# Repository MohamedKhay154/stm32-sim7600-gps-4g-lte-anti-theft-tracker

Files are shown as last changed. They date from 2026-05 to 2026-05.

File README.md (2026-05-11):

# STM32 SIM7600 GPS Tracker

This hobby project is designed to be a practical gadget that can be used in daily life, whether you own an expensive bike or car and want to detect theft once it is parked, or simply want to track anything using GPS and cloud connectivity. 
In this project, I will explain how I developed and built the system.

---

# Overview
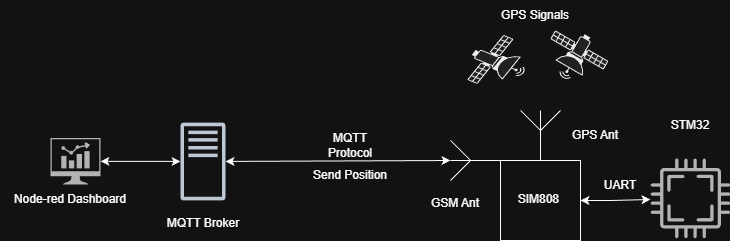
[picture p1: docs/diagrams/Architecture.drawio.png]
System architecture


The STM32 communicates with the SIM7600E module via UART. GPS data is parsed on the MCU and sent either via SMS or published to an MQTT broker. Node-RED processes incoming data and provides visualization and control.

---

# Features

- Custom PCB design
- GPS tracking
- MQTT publish/subscribe
- Geofence/Park mode
- Connection health monitoring
- Modular embedded software design

---

# Hardware
Since this project is intended to be a compact GPS tracker, I wanted to make it as small as possible while using the SIM7600E module. I decided to divide the hardware into two separate PCBs.

The first PCB contains the SIM7600E module and all the required supporting hardware, such as the SIM card holder, antennas, and its dedicated voltage regulator. The second PCB contains the STM32L072 microcontroller and the remaining supporting hardware components. Both PCBs are stacked together and communicate through a common connector interface.

Note: In this page, I will only discuss the SIM7600E board because the second board is still under development. I am currently adding extra features to it, such as a battery charging circuit and a gyroscope. Once it is completed, I will publish it as well. For now, I am using a Nucleo board for prototyping.

## Schematic
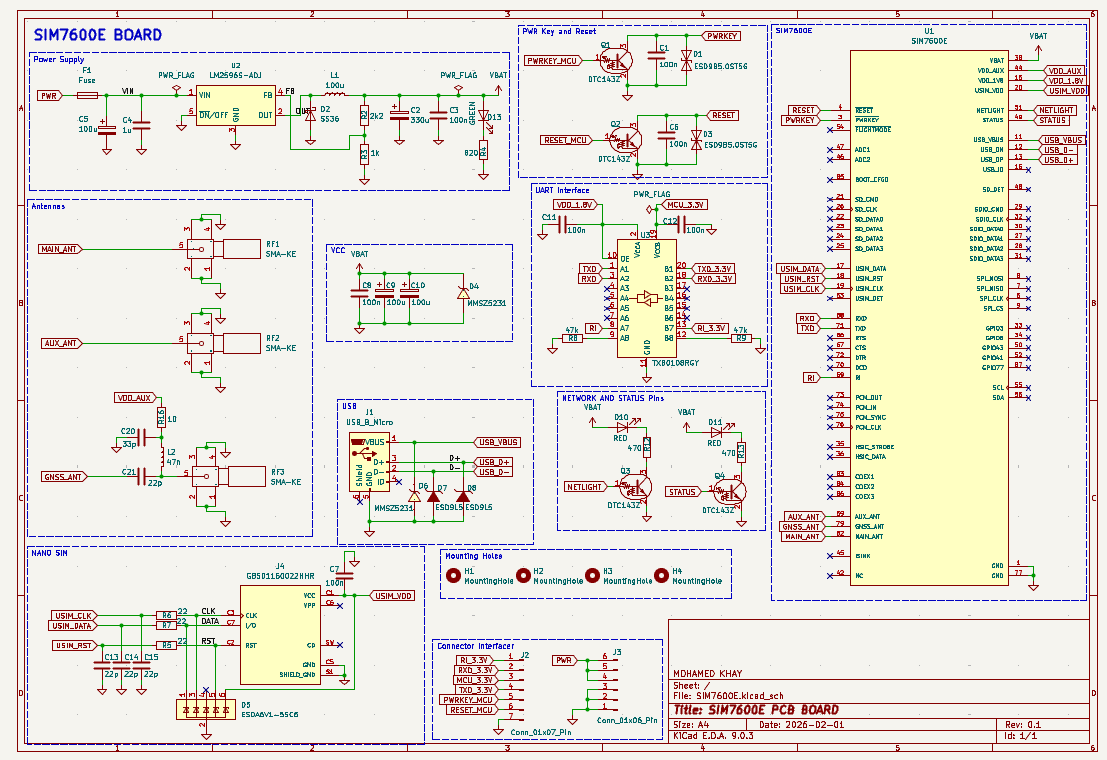
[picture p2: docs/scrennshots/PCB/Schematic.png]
Schematic


The first main step in designing a custom PCB is creating the schematic. The datasheet provided by SIMCom was very helpful, as it includes recommended circuits and components, which made the design process much simpler.

I used the same buck converter recommended in the datasheet, the LM2596S-ADJ, because the board is powered using a 2S LiPo battery, which can provide up to 8.4V when fully charged and around 7.4V typically.

A logic level shifter is used to convert the SIM7600E 1.8V logic levels to 3.3V logic levels, ensuring safe UART communication with the microcontroller.

For the antennas, I chose a much simpler design, except for the GPS antenna, which requires a so-called bias-tee circuit to properly power the active GPS antenna. This circuit was also recommended and explained in the SIMCom datasheet.

Some LEDs were also added to visualize the network status.

In general, the SIM7600E supports many additional features, such as an SD card interface, but I only implemented the features that were necessary for this project.

## Footprints and Layout
<p align="center">
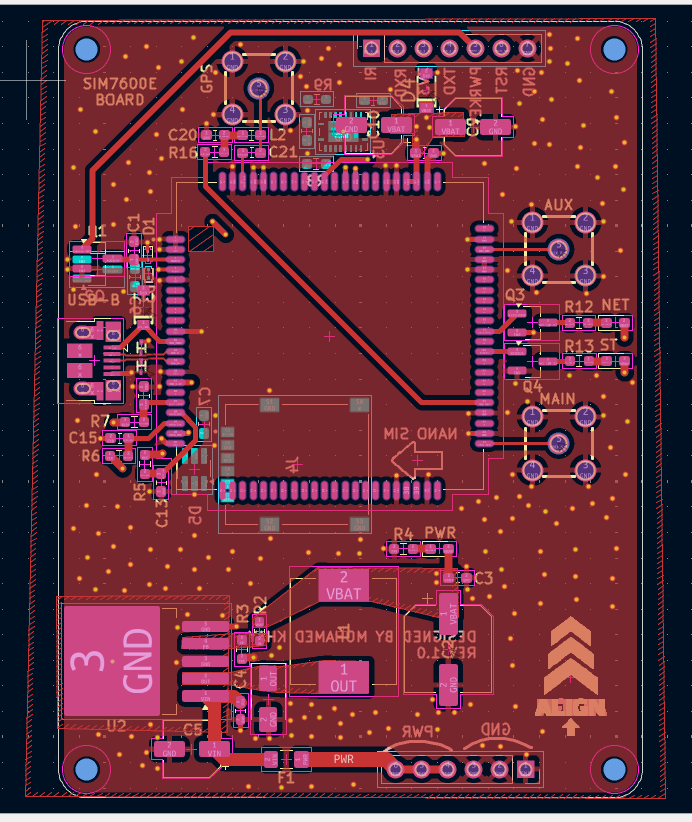
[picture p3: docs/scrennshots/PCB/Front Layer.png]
  
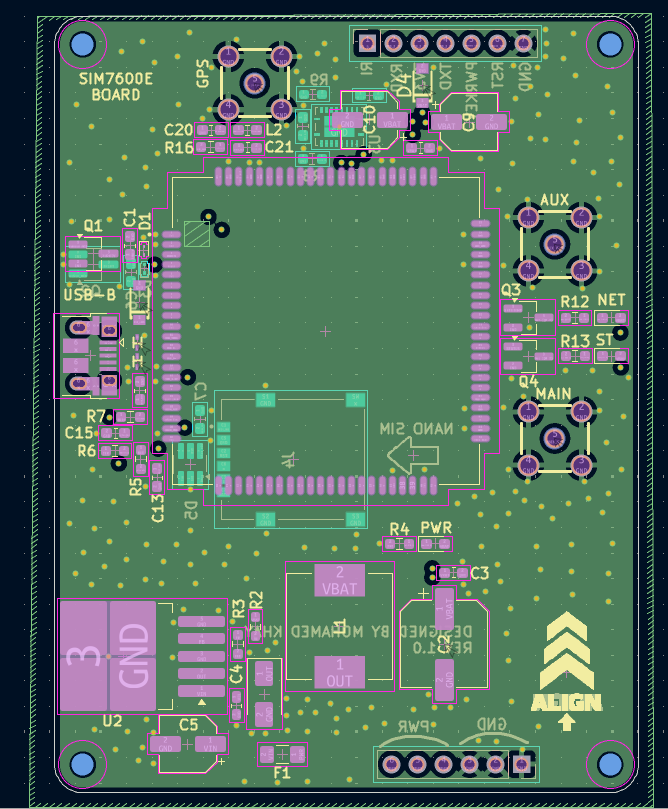
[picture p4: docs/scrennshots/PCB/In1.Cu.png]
  
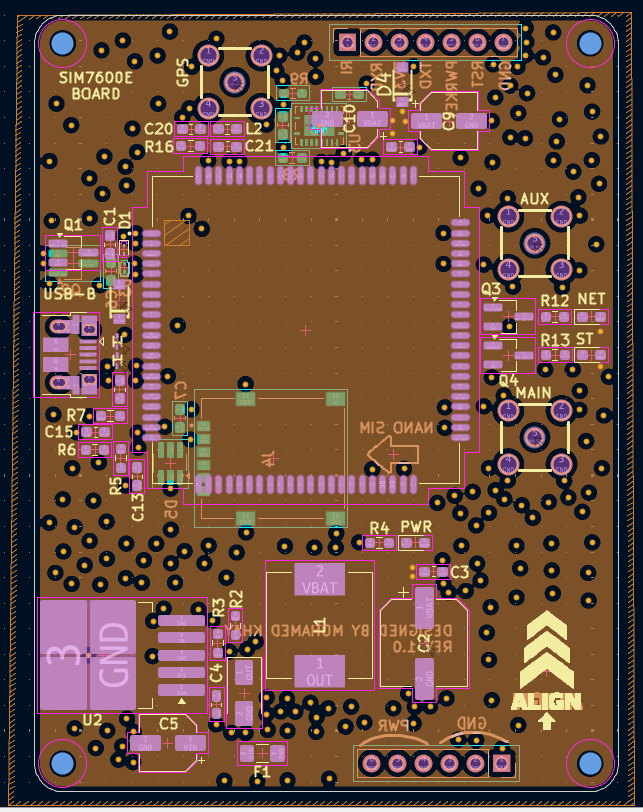
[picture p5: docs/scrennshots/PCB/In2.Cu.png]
  
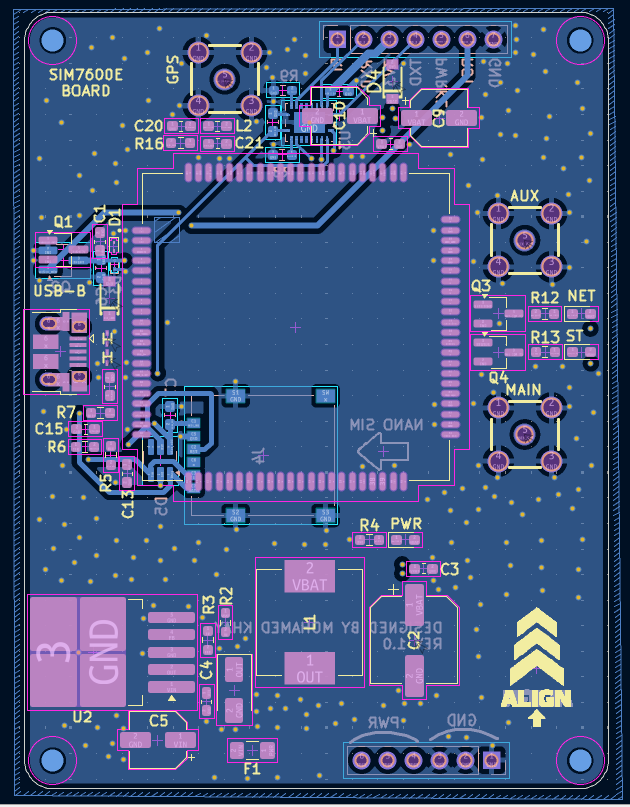
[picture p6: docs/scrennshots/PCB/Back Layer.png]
  
</p>

After reviewing the schematic, the next step is selecting the appropriate footprints. I have included the footprints I used, along with the symbols and 3D models, in the folder PCB Design/SIM7600E.

If this is your first time designing a PCB, like it was for me, avoid making the same mistake I did by choosing footprints that are too small for resistors, capacitors, and LEDs, especially if you plan to solder the board yourself.

For the PCB layout, I chose a 4-layer design to improve performance. The two inner layers are dedicated to the ground plane and power plane. 

This step is very important because a good PCB layout greatly affects the overall performance of the board, especially for the buck converter and high-frequency signals. 

## Manufacturing 

<p align="center">
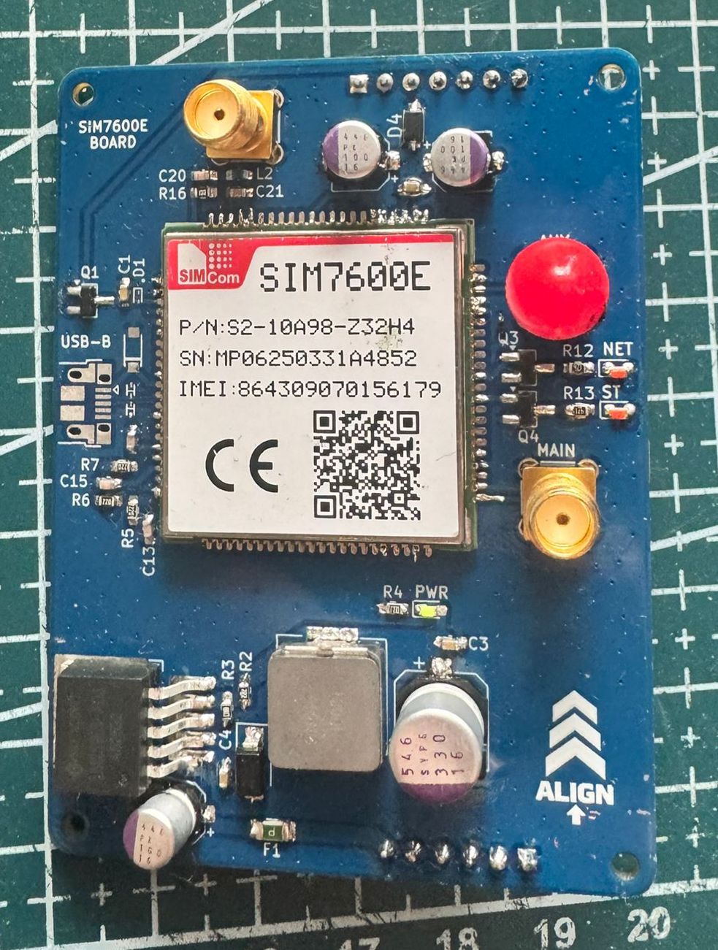
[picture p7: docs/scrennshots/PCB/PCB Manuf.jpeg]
  
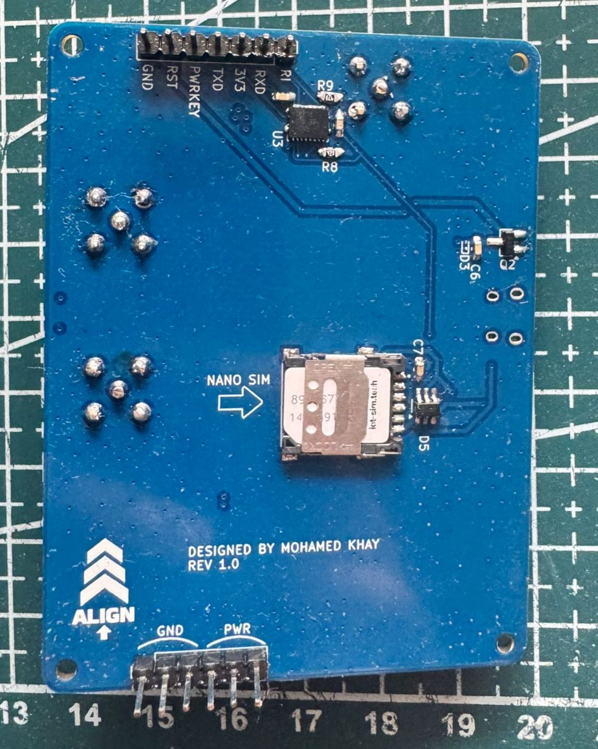
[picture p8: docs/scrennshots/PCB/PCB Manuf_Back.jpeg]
  
</p>

I ordered the PCB from JLCPCB and the components from LCSC, then soldered the board myself.

The BOM and component position files can be found here: `PCB Design/SIM7600E/production`

---

# Software Architecture

## Main Modules

```text
Core/
├── Inc/
  ├── min.h
  ├── SIM7600E.h
  ├── system_fsm.h
  ├── timer.h
  └── log.h
├── Src/
  ├── min.c
  ├── SIM7600E.c
  ├── system_fsm.c
  └── timer.c
```

`SIM7600.h` and `SIM7600.c` contain all the required functions to communicate with the SIM7600E module using UART, including GPS positioning, power control, SMS handling, and MQTT publish/subscribe functionality.

`system_fsm.h` and `system_fsm.c` contain the implementation of the finite state machine, which will be explained in the next section.

`timer.h` and `timer.c` contain the functions related to the timers used for tracking and system monitoring.

`log.h` contains an overridden version of the `printf` function used for logging general information, errors, and communication between the STM32 and the SIM7600E module for debugging purposes.

### Example of the logging interface during the TRACKING state.
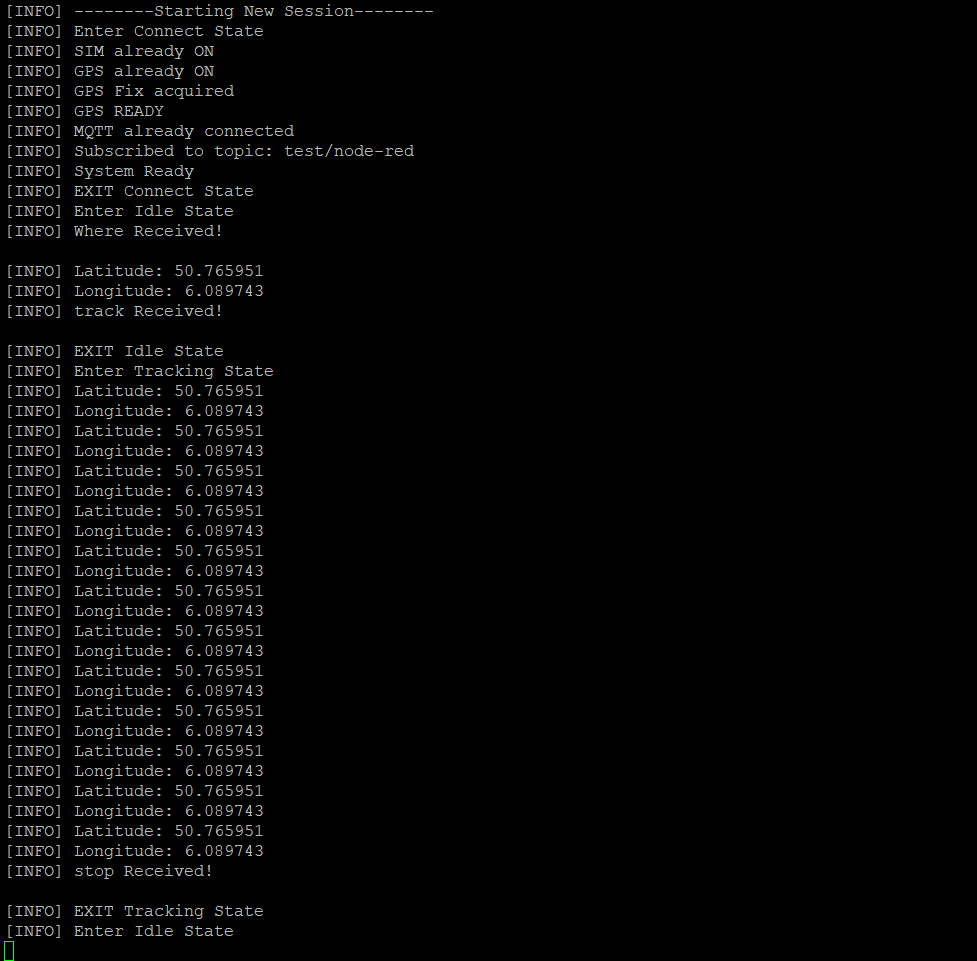
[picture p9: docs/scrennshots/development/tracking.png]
log


---

# State Machine

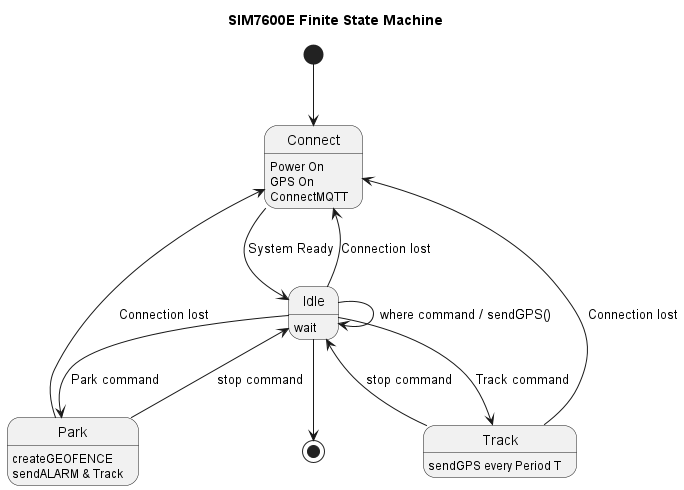
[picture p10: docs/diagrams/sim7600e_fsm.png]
FSM


The firmware uses an event-driven finite state machine.

## States

- CONNECT
- IDLE
- TRACK
- PARK

## Description

The CONNECT state is responsible for checking the status of the system components. It verifies whether the SIM module is powered, whether the network and MQTT connection are established, and whether the GPS is enabled. If any component is not ready, the state attempts to initialize or reconnect it accordingly. Once everything is ready, the system transitions to the IDLE state, where it waits for incoming events or commands.

If a `WHERE` command is received, the device immediately sends its current GPS position.

If a `TRACK` command is received, the system transitions to the TRACK state. In this state, a timer is started, and the device periodically sends its GPS position until a `STOP` command is received, after which the system returns to the IDLE state.

If a `PARK` command is received, the system transitions to the PARK state. First, the current GPS position is sent in order to create a geofence around the parked location (explained later in the Node-RED section). A timer is then started to continuously monitor the device position. If a geofence breach occurs, meaning the tracked device moves away from the allowed area, an alert is sent and the system automatically switches to TRACK mode since this may indicate a potential theft attempt.

In all states, another timer called `sysHealth_Timer` runs every 5 seconds to monitor the health of the communication stack. If a connection loss is detected in any state, the system automatically transitions back to the CONNECT state to recover the connection and then returns to the previous operational state.

## Why State Machine ?

Since this project is intended to work as an anti-theft tracker, it contains several different states and operating modes. Using a state machine makes the system more organized, prevents illogical scenarios, and makes the firmware easier to extend in the future.

For example, new subtasks, events, or operating modes can be added more easily. I also plan to allow the user to select these modes through hardware buttons, so having a state-machine-based architecture will make this feature easier to implement later.

---
# Node-Red
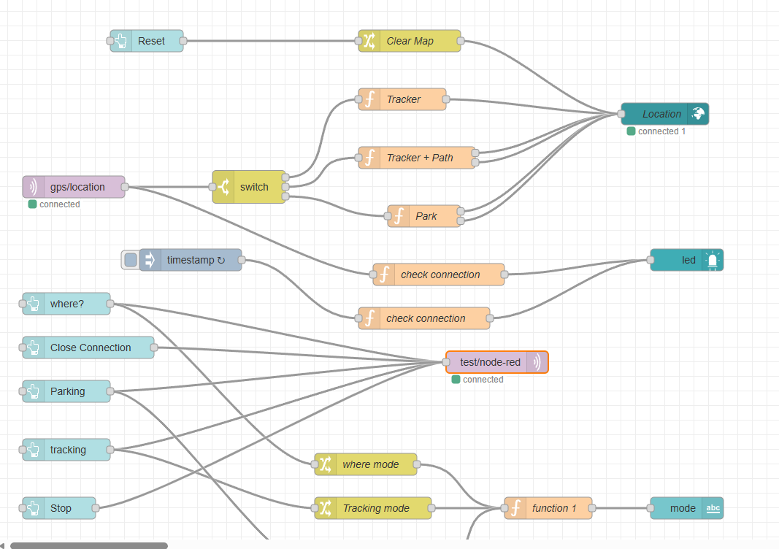
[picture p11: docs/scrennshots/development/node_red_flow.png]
Flow

Node-RED is widely used in IoT and network-related applications, and it supports the MQTT protocol natively. In addition, it is very easy to use and implement thanks to its drag-and-drop interface and simple JavaScript programming.

Node-RED subscribes to the same MQTT topic used by the SIM7600E module, receives the GPS position data, and then sends it as JSON data to a world map dashboard for visualization.

I also added support for different operating modes because each mode requires a specific type of visualization. For example, in TRACK mode, the system displays the traveled path, while in PARK mode, it creates a circular geofence around the parked position. The different visualizations are shown in the following pictures.

<p align="center">
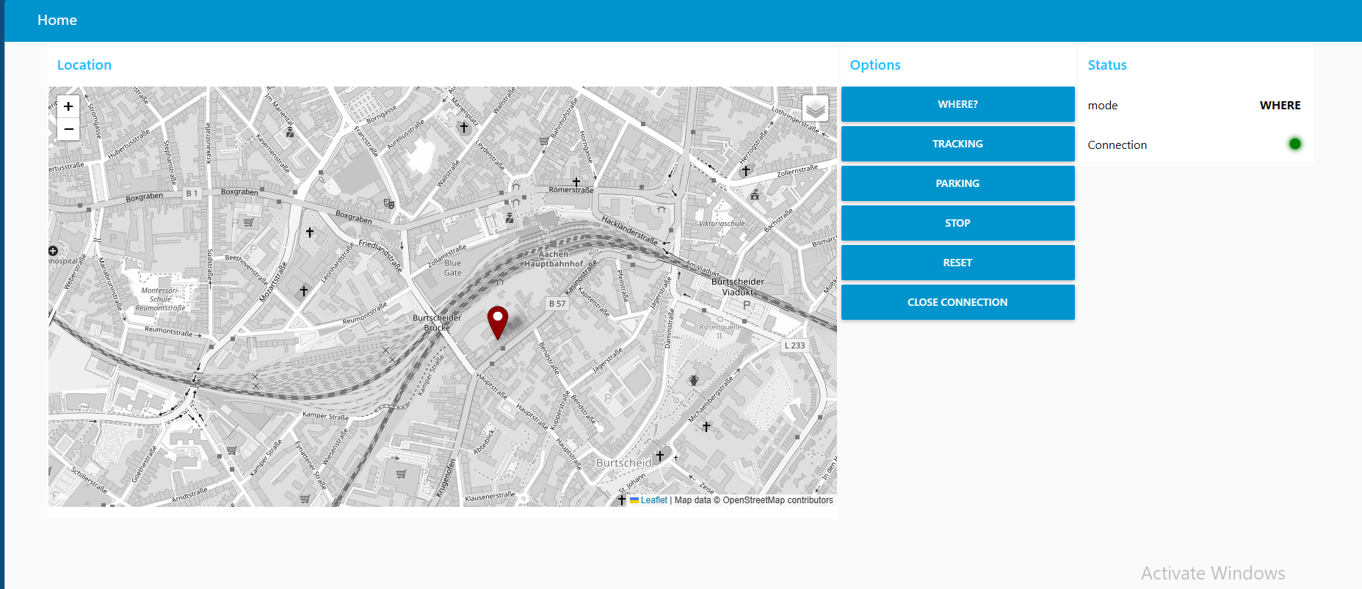
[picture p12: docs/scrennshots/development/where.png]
  
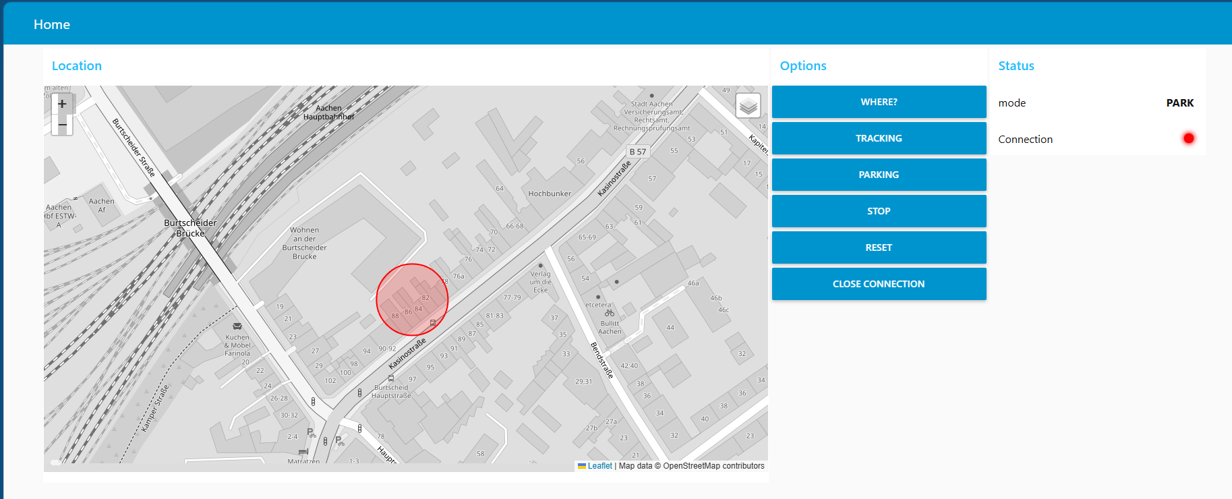
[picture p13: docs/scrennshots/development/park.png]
  
</p>

---

# Future Improvements

- Add a gyroscope/accelerometer for PARK mode in order to detect even the smallest movements. GPS data always has some tolerance and can sometimes vary by up to several meters, making it unreliable for immediate theft detection. By using a gyroscope or motion sensor, the system could instantly detect movement and then rely on GPS for long-distance tracking.
- Add a database to the Node-RED dashboard to give the project memory capabilities, allowing users to save and review previous trips, routes, and tracking history.
- Add battery monitoring functionality to the second PCB in order to monitor battery level and improve power management.

---

# Author

Mohamed Khay
Computer Engineering Student

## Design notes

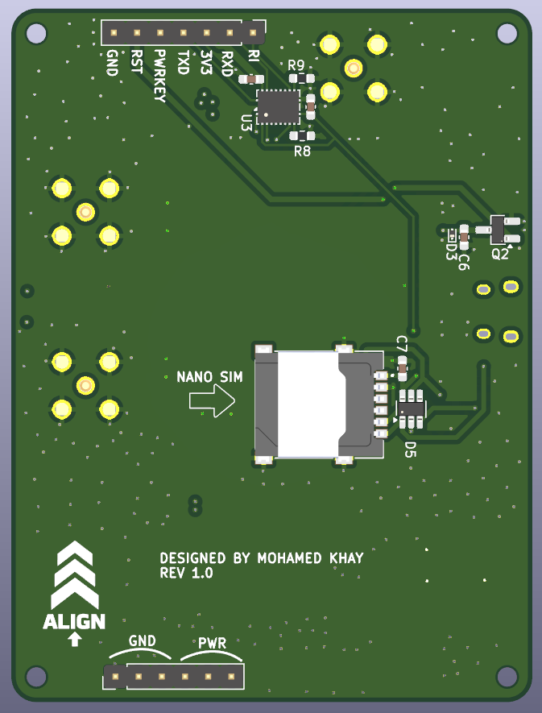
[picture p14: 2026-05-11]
docs/scrennshots/PCB/3D_Back.png

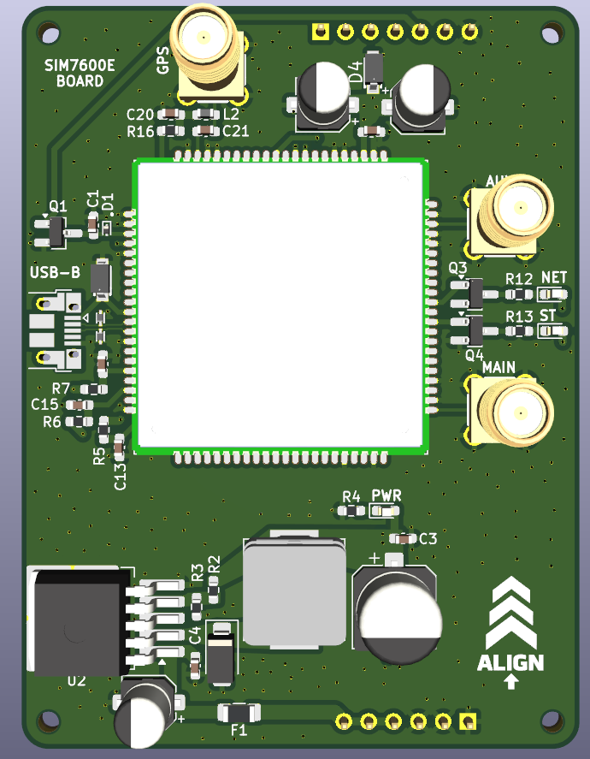
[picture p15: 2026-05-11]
docs/scrennshots/PCB/3D.png

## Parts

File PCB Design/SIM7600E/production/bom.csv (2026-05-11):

Designator | Footprint | Quantity | Value | LCSC Part #
C1, C11, C12, C3, C6, C7, C8 | 0603 | 7 | 100n
C10, C5, C9 | CP_Elec_5x5.9 | 3 | 100u
C13, C14, C15, C21 | 0603 | 4 | 22p
C2 | CP_Elec_8x6.9 | 1 | 330u
C20 | 0603 | 1 | 33p
C4 | 0603 | 1 | 1u
D1, D3 | D_SOD-923 | 2 | ESD9B5.0ST5G
D10, D11 | 0603 | 2 | RED
D13 | 0603 | 1 | GREEN
D2 | D_SMA | 1 | SS36
D4, D6 | SOD-123_L2.8-W1.8-LS3.7-RD | 2 | MMSZ5231
D5 | SOT-23-6_Handsoldering | 1 | ESDA6V1-5SC6
D7, D8 | SOD-923_L0.8-W0.6-LS1.0-RD | 2 | ESD9L5
F1 | 1206 | 1 | Fuse
J1 | USB_Micro-B_Amphenol_10103594-0001LF_Horizontal | 1 | USB_B_Micro
J2 | PinHeader_1x07_P2.54mm_Vertical | 1 | Conn_01x07_Pin
J3 | PinHeader_1x06_P2.54mm_Vertical | 1 | Conn_01x06_Pin
J4 | AMPHENOL_G85D1160022HHR | 1 | G85D1160022HHR
L1 | L_Vishay_IHLP-4040 | 1 | 100u
L2 | 0603 | 1 | 47n
Q1, Q2, Q3, Q4 | SOT-23_Handsoldering | 4 | DTC143Z
R12, R13 | 0603 | 2 | 470
R16 | 0603 | 1 | 10
R2 | 0603 | 1 | 2k2
R3 | 0603 | 1 | 1k
R4 | 0603 | 1 | 820
R5, R6, R7 | 0603 | 3 | 22
R8, R9 | 0603 | 2 | 47k
RF1, RF2, RF3 | SMA-TH_SMA-KE-5 | 3 | SMA-KE
U1 | XCVR_SIM7600E | 1 | SIM7600E
U2 | TO-263-5_TabPin3 | 1 | LM2596S-ADJ
U3 | Texas_RGY_R-PVQFN-N20_EP2.05x3.05mm | 1 | TXB0108RGY

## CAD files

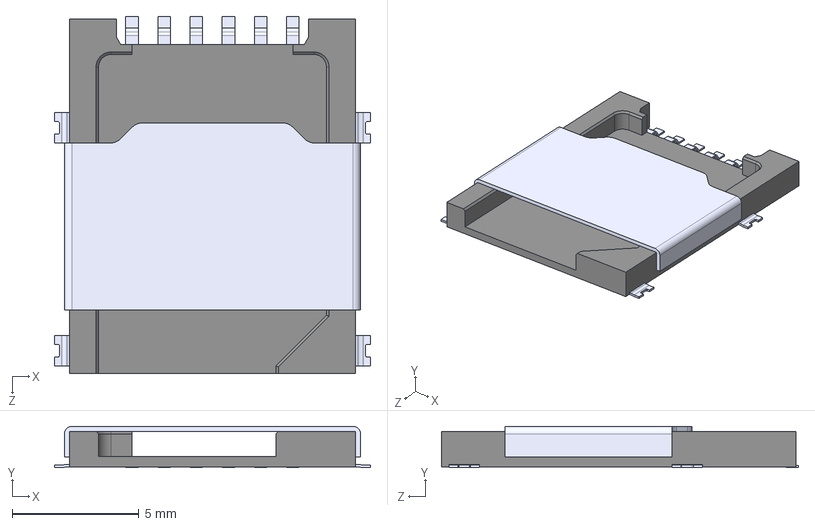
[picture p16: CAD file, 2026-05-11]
PCB Design/SIM7600E/SIM7600E_3D_MODELS/G85D1160022HHR.step
12.5 x 1.63 x 14.1 mm
G85D1160022HHR-Foot 0.5 x 6
G85D1160022HHR-Housing
G85D1160022HHR-shell
G85D1160022HHR-SW x 4

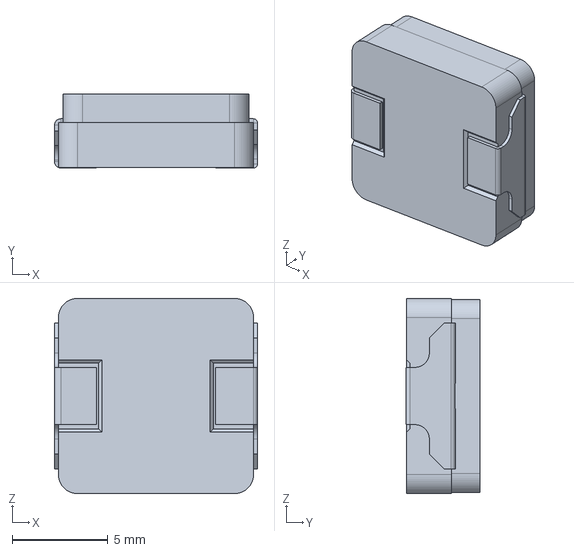
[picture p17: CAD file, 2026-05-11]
PCB Design/SIM7600E/SIM7600E_3D_MODELS/ihlp4040dzer101m11.stp
10.6 x 3.87 x 10.2 mm

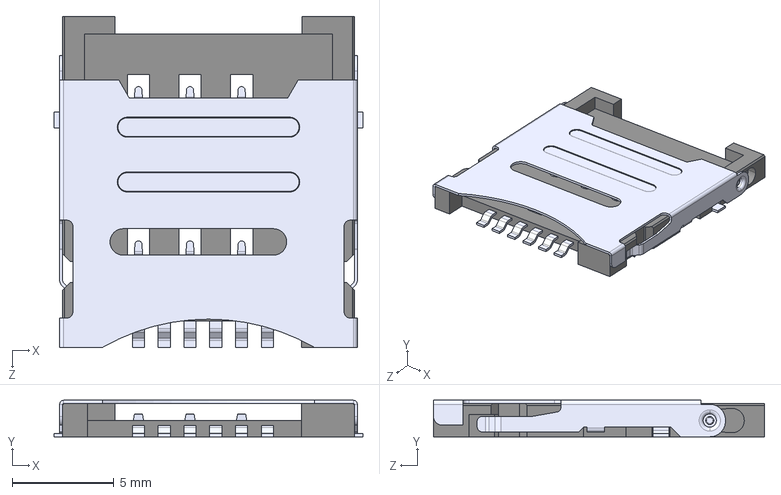
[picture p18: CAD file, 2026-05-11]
PCB Design/SIM7600E/SIM7600E_3D_MODELS/SMC-216.step
15.2 x 1.80 x 16.3 mm

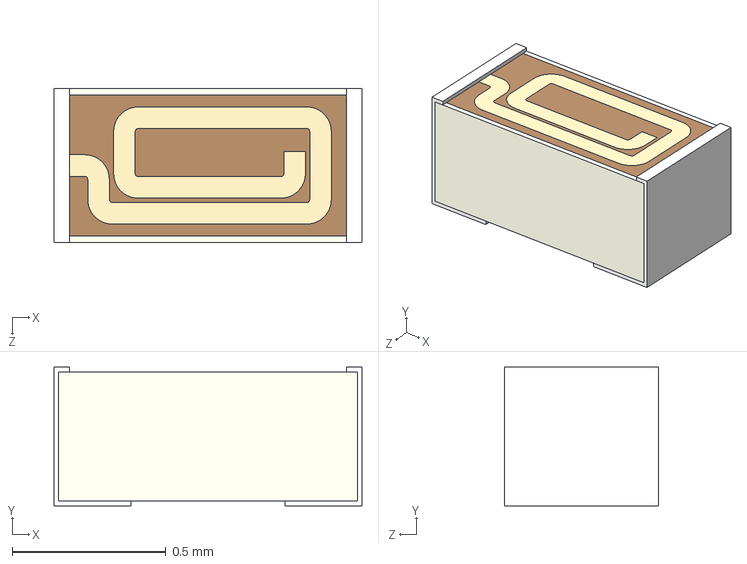
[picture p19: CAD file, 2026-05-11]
PCB Design/SIM7600E/SIM7600E_3D_MODELS/LXES15AAA1-153.STEP
1.00 x 0.45 x 0.5 mm

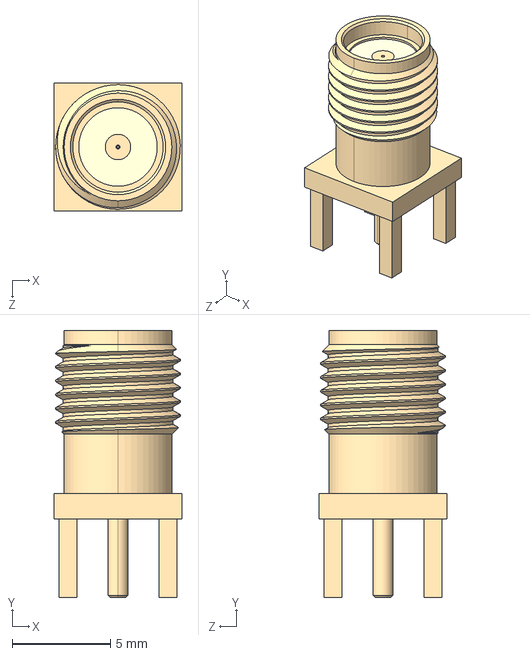
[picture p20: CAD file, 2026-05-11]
PCB Design/SIM7600E/SIM7600E_3D_MODELS/SMA_CONNECTOR.step
6.50 x 13.6 x 6.50 mm

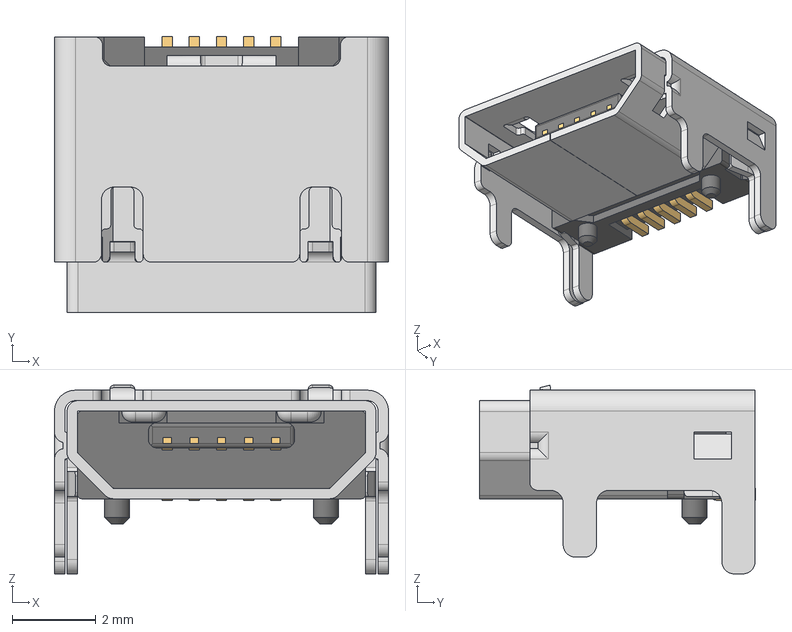
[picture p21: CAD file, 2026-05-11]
PCB Design/SIM7600E/SIM7600E_3D_MODELS/USB_Micro-B_629105150521.stp
8.00 x 6.60 x 4.52 mm
629105150521_Housing
629105150521_Pin1 x 4
629105150521_Pin2
629105150521_Shielding2
629105150521_Shielding

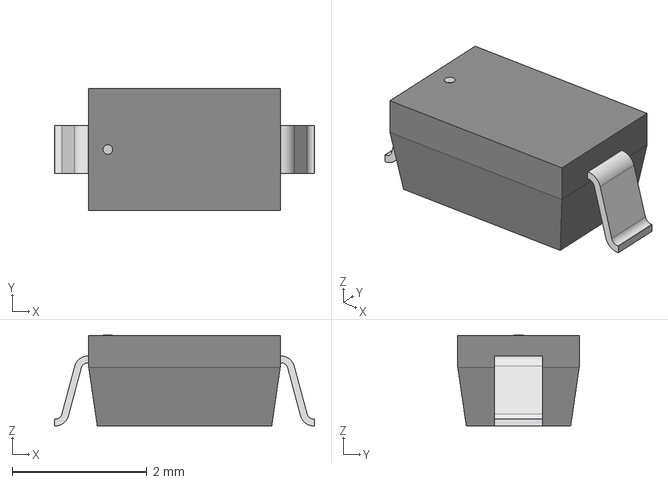
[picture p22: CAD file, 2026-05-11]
PCB Design/SIM7600E/SIM7600E_3D_MODELS/SOD-123_ONS.step
3.86 x 1.80 x 1.35 mm

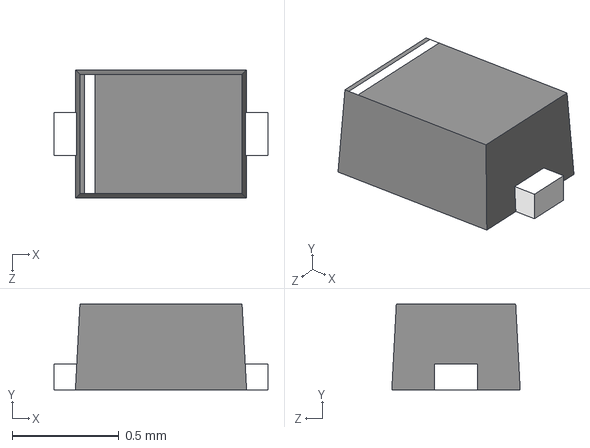
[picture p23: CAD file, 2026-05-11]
PCB Design/SIM7600E/SIM7600E_3D_MODELS/ESD9L5.0ST5G.step
1 x 0.4 x 0.6 mm

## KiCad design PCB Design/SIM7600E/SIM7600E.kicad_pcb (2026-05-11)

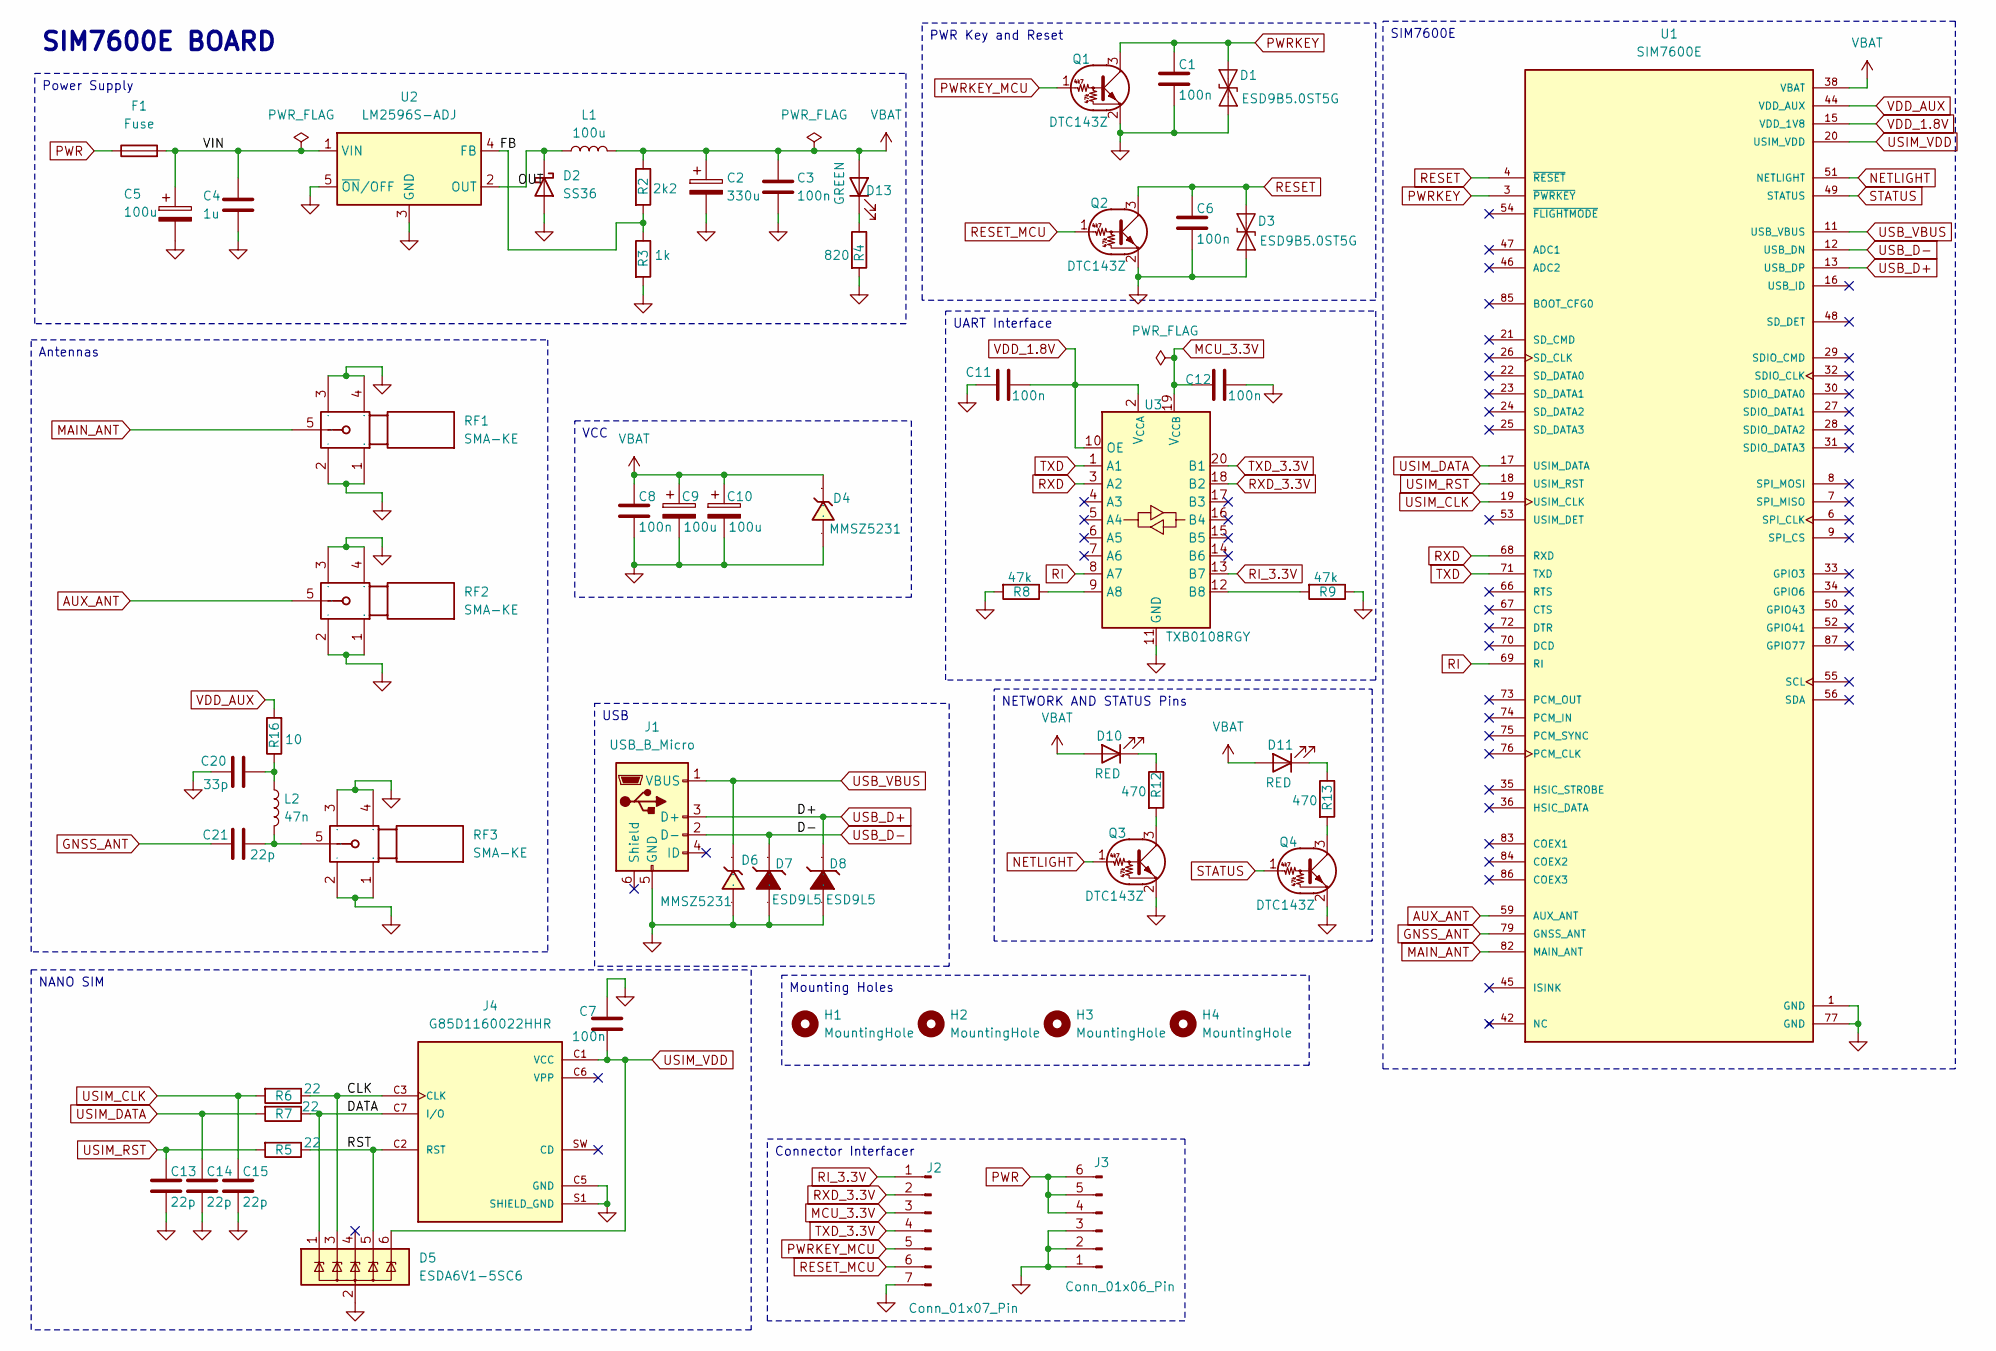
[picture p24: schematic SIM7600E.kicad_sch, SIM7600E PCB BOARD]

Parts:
C1, C3, C6, C7, C8, C11, C12: 100n; C_0603_1608Metric_Pad1.08x0.95mm_HandSolder
C2: 330u; CP_Elec_8x6.9; jlcpcb C3274687
C4: 1u; C_0603_1608Metric_Pad1.08x0.95mm_HandSolder
C5, C9, C10: 100u; CP_Elec_5x5.9; jlcpcb C542291
C13, C14, C15, C21: 22p; C_0603_1608Metric_Pad1.08x0.95mm_HandSolder
C20: 33p; C_0603_1608Metric_Pad1.08x0.95mm_HandSolder
D1, D3: ESD9B5.0ST5G; D_SOD-923
D2: SS36; D_SMA
D4, D6: MMSZ5231; SOD-123_L2.8-W1.8-LS3.7-RD; Manufacturer Part MMSZ5231BT1G
D5: ESDA6V1-5SC6; SOT-23-6_Handsoldering
D7, D8: ESD9L5; SOD-923_L0.8-W0.6-LS1.0-RD; Manufacturer Part ESD9L5.0ST5G
D10, D11: RED; LED_0603_1608Metric_Pad1.05x0.95mm_HandSolder; JLCPCB C7371906
D13: GREEN; LED_0603_1608Metric_Pad1.05x0.95mm_HandSolder; JLCPCB C7371905
F1: Fuse; Fuse_1206_3216Metric_Pad1.42x1.75mm_HandSolder
H1, H2, H3, H4: MountingHole; MountingHole_2.1mm
J1: USB_B_Micro; USB_Micro-B_Amphenol_10103594-0001LF_Horizontal
J2: Conn_01x07_Pin; PinHeader_1x07_P2.54mm_Vertical
J3: Conn_01x06_Pin; PinHeader_1x06_P2.54mm_Vertical
J4: G85D1160022HHR; AMPHENOL_G85D1160022HHR; PARTREV AX3; DigiKey_Part_Number 664-G85D1160022HHRCT-ND
L1: 100u; L_Vishay_IHLP-4040
L2: 47n; L_0603_1608Metric_Pad1.05x0.95mm_HandSolder; JLCPCB C98077
Q1, Q2, Q3, Q4: DTC143Z; SOT-23_Handsoldering; JLCPCB C15236
R2: 2k2; R_0603_1608Metric_Pad0.98x0.95mm_HandSolder
R3: 1k; R_0603_1608Metric_Pad0.98x0.95mm_HandSolder
R4: 820; R_0603_1608Metric_Pad0.98x0.95mm_HandSolder
R5, R6, R7: 22; R_0603_1608Metric_Pad0.98x0.95mm_HandSolder
R8, R9: 47k; R_0603_1608Metric_Pad0.98x0.95mm_HandSolder
R12, R13: 470; R_0603_1608Metric_Pad0.98x0.95mm_HandSolder
R16: 10; R_0603_1608Metric_Pad0.98x0.95mm_HandSolder
RF1, RF2, RF3: SMA-KE; SMA-TH_SMA-KE-5; Manufacturer Part SMA-KE-5
U1: SIM7600E; XCVR_SIM7600E; PARTREV V1.03
U2: LM2596S-ADJ; TO-263-5_TabPin3; JLCPCB C5349987
U3: TXB0108RGY; Texas_RGY_R-PVQFN-N20_EP2.05x3.05mm

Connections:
/CLK: D5.3 (IO2), J4.C3 (CLK), R6.1
/DATA: D5.1 (IO1), J4.C7 (I/O), R7.1
/FB: R2.2, R3.1, U2.4 (FB)
/OUT: D2.1 (K), L1.1, U2.2 (OUT)
/RST: D5.5 (IO4), J4.C2 (RST), R5.1
/VIN: C4.1, C5.1, F1.2, U2.1 (VIN)
AUX_ANT: RF2.5, U1.59 (AUX_ANT)
GND: C1.2, C2.2, C3.2, C4.2, C5.2, C6.2, C7.1, C8.2, C9.2, C10.2, C11.1, C12.2, C13.2, C14.2, C15.2, C20.1, D1.1 (A1), D2.2 (A), D3.1 (A1), D4.2 (A), D5.2 (GND), D6.2 (A), D7.2 (A), D8.2 (A), J1.5 (GND), J2.7, J3.1, J3.2, J3.3, J4.C5 (GND), J4.S1 (SHIELD_GND), J4.S2 (SHIELD_GND), J4.S3 (SHIELD_GND), Q1.2 (E), Q2.2 (E), Q3.2 (E), Q4.2 (E), R3.2, R4.2, R8.2, R9.1, RF1.1, RF1.2, RF1.3, RF1.4, RF2.1, RF2.2, RF2.3, RF2.4, RF3.1, RF3.2, RF3.3, RF3.4, U1.1 (GND), U1.2 (GND1), U1.5 (GND1), U1.10 (GND1), U1.14 (GND1), U1.37 (GND1), U1.40 (GND1), U1.41 (GND1), U1.43 (GND1), U1.57 (GND1), U1.58 (GND1), U1.60 (GND1), U1.61 (GND1), U1.64 (GND1), U1.65 (GND1), U1.77 (GND), U1.78 (GND2), U1.80 (GND2), U1.81 (GND2), U2.3 (GND), U2.5 (~ON/OFF), U3.11 (GND), U3.21 (GND)
GNSS_ANT: C21.1, U1.79 (GNSS_ANT)
MAIN_ANT: RF1.5, U1.82 (MAIN_ANT)
MCU_3.3V: C12.1, J2.3, U3.19 (V_{CCB})
NETLIGHT: Q3.1 (B), U1.51 (NETLIGHT)
unnamed: C20.2, L2.1, R16.1
unnamed: C21.2, L2.2, RF3.5
unnamed: D10.1 (K), R12.1
unnamed: D11.1 (K), R13.1
unnamed: D13.1 (K), R4.1
unnamed: Q3.3 (C), R12.2
unnamed: Q4.3 (C), R13.2
unnamed: R8.1, U3.9 (A8)
unnamed: R9.2, U3.12 (B8)
PWR: F1.1, J3.4, J3.5, J3.6
PWRKEY: C1.1, D1.2 (A2), Q1.3 (C), U1.3 (~PWRKEY)
PWRKEY_MCU: J2.5, Q1.1 (B)
RESET: C6.1, D3.2 (A2), Q2.3 (C), U1.4 (~RESET)
RESET_MCU: J2.6, Q2.1 (B)
RI: U1.69 (RI), U3.8 (A7)
RI_3.3V: J2.1, U3.13 (B7)
RXD: U1.68 (RXD), U3.3 (A2)
RXD_3.3V: J2.2, U3.18 (B2)
STATUS: Q4.1 (B), U1.49 (STATUS)
TXD: U1.71 (TXD), U3.1 (A1)
TXD_3.3V: J2.4, U3.20 (B1)
USB_D+: D8.1 (C), J1.3 (D+), U1.13 (USB_DP)
USB_D-: D7.1 (C), J1.2 (D-), U1.12 (USB_DN)
USB_VBUS: D6.1 (K), J1.1 (VBUS), U1.11 (USB_VBUS)
USIM_CLK: C15.1, R6.2, U1.19 (USIM_CLK)
USIM_DATA: C14.1, R7.2, U1.17 (USIM_DATA)
USIM_RST: C13.1, R5.2, U1.18 (USIM_RST)
USIM_VDD: C7.2, D5.6 (IO5), J4.C1 (VCC), U1.20 (USIM_VDD)
VBAT: C2.1, C3.1, C8.1, C9.1, C10.1, D4.1 (K), D10.2 (A), D11.2 (A), D13.2 (A), L1.2, R2.1, U1.38 (VBAT), U1.39 (VBAT), U1.62 (VBAT), U1.63 (VBAT)
VDD_1.8V: C11.2, U1.15 (VDD_1V8), U3.2 (V_{CCA}), U3.10 (OE)
VDD_AUX: R16.2, U1.44 (VDD_AUX)

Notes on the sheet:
SIM7600E BOARD
PWR Key and Reset
SIM7600E
Antennas
NANO SIM
NETWORK AND STATUS Pins
UART Interface
VCC
USB
Connector Interfacer
Mounting Holes
Power Supply

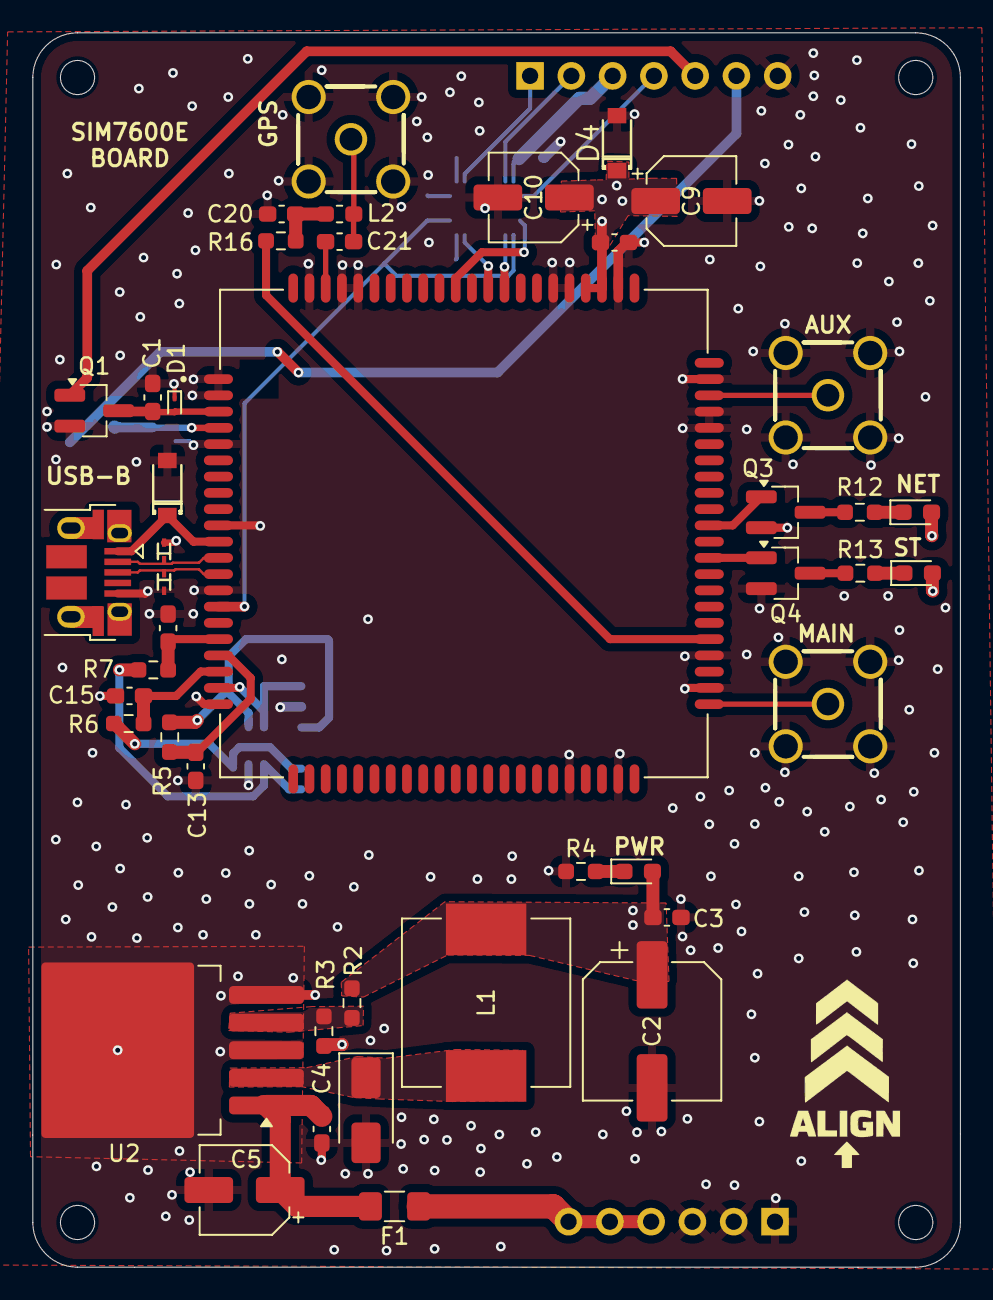
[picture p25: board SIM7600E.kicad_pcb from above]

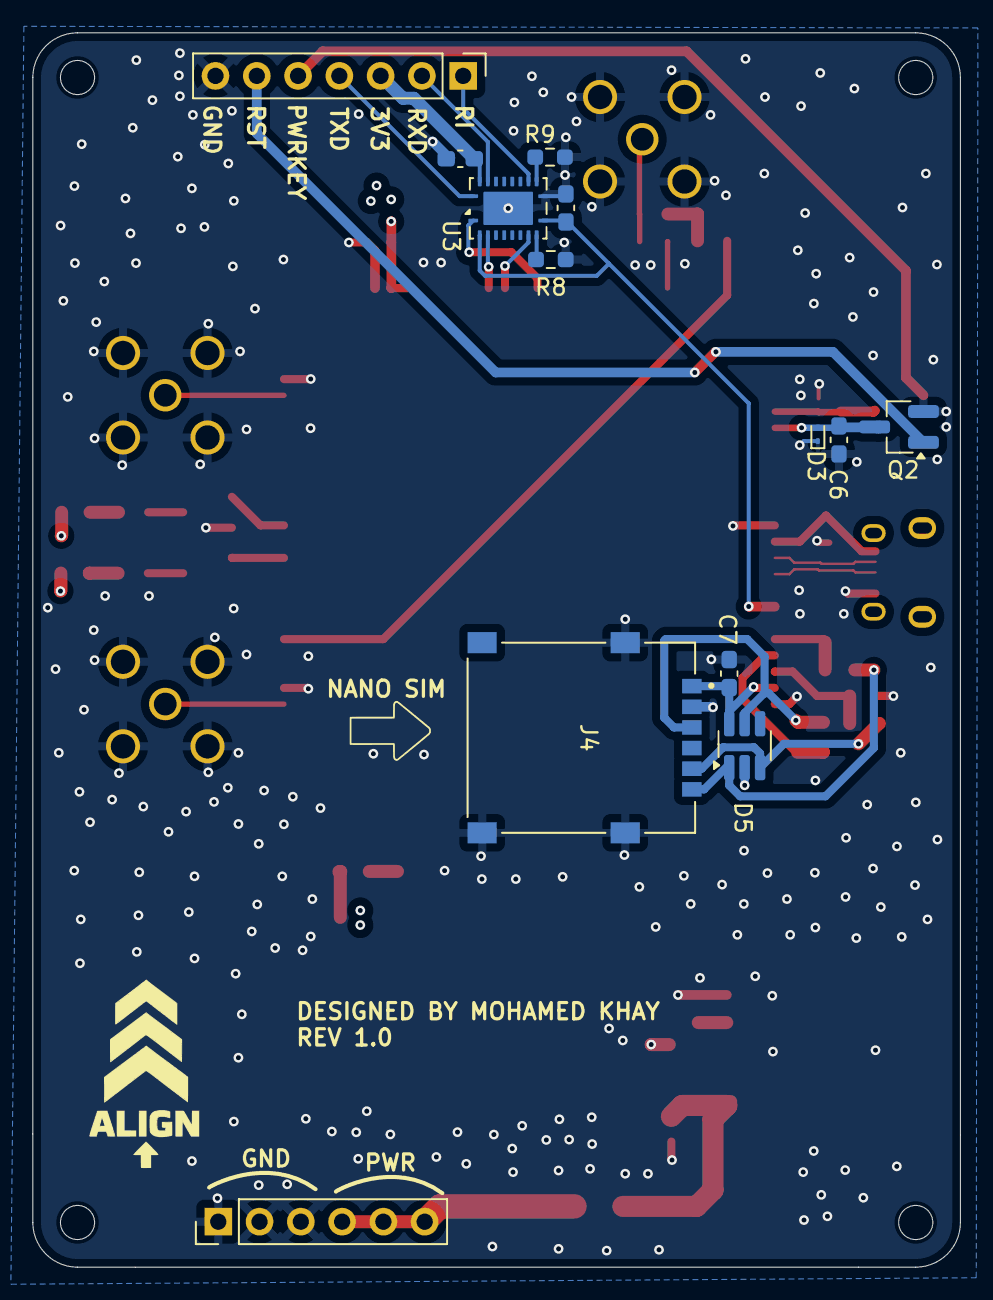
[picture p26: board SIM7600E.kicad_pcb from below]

Board: 4 copper layers, 57.1 x 76.0 mm, 60 parts (13 on the bottom side), 43 nets.

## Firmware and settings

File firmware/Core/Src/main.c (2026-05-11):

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
/* Includes ------------------------------------------------------------------*/
#include "main.h"

/* USER CODE BEGIN Includes */
#include "log.h"
#include "SIM7600E.h"
#include "system_fsm.h"
#include "timer.h"
/* USER CODE END Includes */

TIM_HandleTypeDef htim2;
TIM_HandleTypeDef htim3;

UART_HandleTypeDef huart2;
UART_HandleTypeDef huart3;

void SystemClock_Config(void);
static void MX_GPIO_Init(void);
static void MX_USART2_UART_Init(void);
static void MX_USART3_UART_Init(void);
static void MX_TIM2_Init(void);
static void MX_TIM3_Init(void);
/* USER CODE BEGIN PFP */
int _write(int file, char *ptr, int len)
 {
     HAL_UART_Transmit(&huart2, (uint8_t *)ptr, len, 100);
     return len;
 }

/* USER CODE END PFP */

/**
  * @brief  The application entry point.
  * @retval int
  */
int main(void)
{

  /* MCU Configuration--------------------------------------------------------*/

  /* Reset of all peripherals, Initializes the Flash interface and the Systick. */
  HAL_Init();

  /* USER CODE BEGIN Init */
  SIM_UART_Init(&huart3);
  Tracking_Timer_Init(&htim2);
  sysHealth_Timer_Init(&htim2);

  /* USER CODE END Init */

  /* Configure the system clock */
  SystemClock_Config();

  /* Initialize all configured peripherals */
  MX_GPIO_Init();
  MX_USART2_UART_Init();
  MX_USART3_UART_Init();
  MX_TIM2_Init();
  MX_TIM3_Init();
  /* USER CODE BEGIN 2 */
  LOG_INFO("--------Starting New Session--------");
  //sendSMS();
  State_Connect_Enter();

  /* USER CODE END 2 */

  /* Infinite loop */
  /* USER CODE BEGIN WHILE */
	while (1) {


		Event_t ev = Event_Wait();
		//HAL_Delay(500);

		if (ev == EVENT_NONE) {
			continue;
		}

		switch (current_state) {

		case STATE_CONNECT:
			State_Connect_HandleEvent(ev);
			break;
		case STATE_IDLE:
			State_Idle_HandleEvent(ev);
			break;

		case STATE_TRACKING:
			State_Tracking_HandleEvent(ev);
			break;

		case STATE_PARK:
			State_Park_HandleEvent(ev);
			break;
		}

		/*if (checkCommand("Where")){
			break;
		}else {
			//LOG_INFO("waiting...");
			HAL_Delay(1000);
			continue;
		}*/

    /* USER CODE END WHILE */

    /* USER CODE BEGIN 3 */
	}
  /* USER CODE END 3 */
}

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


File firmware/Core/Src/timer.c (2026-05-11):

/*
 * timer.c
 *
 *  Created on: May 9, 2026
 *      Author: Mohamed
 */


#include "timer.h"
#include "stm32l4xx_hal.h"

static TIM_HandleTypeDef *tracking_timer;
volatile bool tracking_timer_flag = false;

static TIM_HandleTypeDef *sysHealth_timer;
volatile bool sysHealth_timer_flag = false;


void HAL_TIM_PeriodElapsedCallback(TIM_HandleTypeDef *htim)
{
    if (htim->Instance == TIM2) {
    	tracking_timer_flag = true;
    }
    if (htim->Instance == TIM3) {
    	//watchdog_timer_flag = true; // signal event to FSM
        }
}


void Tracking_Timer_Init(TIM_HandleTypeDef *htim) {
	tracking_timer = htim;
}


void sysHealth_Timer_Init(TIM_HandleTypeDef *htim) {
	sysHealth_timer = htim;
}


void Tracking_Timer_Start()
{
    HAL_TIM_Base_Start_IT(tracking_timer);
    tracking_timer_flag = false;
}


void sysHealth_Timer_Start()
{
    HAL_TIM_Base_Start_IT(sysHealth_timer);
    sysHealth_timer_flag = false;
}

/**
 * @brief Stop the timer
 */
void Tracking_Timer_Stop()
{
    HAL_TIM_Base_Stop_IT(tracking_timer);
    tracking_timer_flag = false;
}

void sysHealth_Timer_Stop()
{
    HAL_TIM_Base_Stop_IT(sysHealth_timer);
    sysHealth_timer_flag = false;
}

bool Tracking_Timer_HasElapsed()
{
    if (tracking_timer_flag) {
    	tracking_timer_flag = false;
        return true;
    }
    return false;
}

bool sysHealth_Timer_HasElapsed()
{
    if (sysHealth_timer_flag) {
    	sysHealth_timer_flag = false;
        return true;
    }
    return false;
}

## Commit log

2026-05-11 Added Timer / FSM Repair
2026-05-11 pcb files upload
    [ESD9L5.0ST5G.step, G85D1160022HHR.step, LXES15AAA1-153.STEP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]
2026-05-11 Rename node red flow.png to node_red_flow.png

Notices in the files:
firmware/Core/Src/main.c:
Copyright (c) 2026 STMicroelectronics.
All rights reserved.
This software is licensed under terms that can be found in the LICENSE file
